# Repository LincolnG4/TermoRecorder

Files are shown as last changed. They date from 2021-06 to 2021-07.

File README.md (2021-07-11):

# TermoRecorder
The arduino records measurements from the thermocouples. It can run 4 measurements simultaneously. The measurements are saved into SD card in a '.CSV' file. A desktop software based on python creates an ETL pipeline to generate a dashboard to analyzes

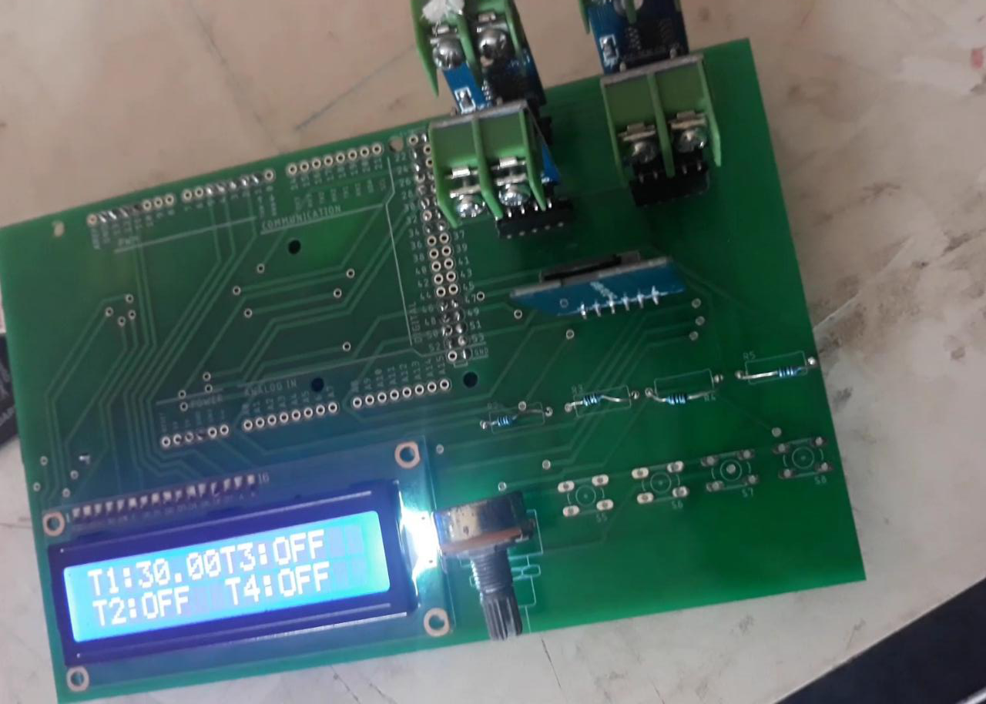
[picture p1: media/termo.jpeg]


## COMPONENTS :gear: 

- 1x Arduino Mega 2560
- 1x SD card module 
- 1x Display LCD 16x2
- 1x Potentiometer 10kOhms
- 4x 300Ω Resistors 
- 4x Module Max6675 K
- 4x Push Buttons

## PINOUT

| MAX6675 | MODULO 1 | MODULO 2 | MODULO 3 |  MODULO 4 |
| :--- | :----: | :----: | :----: | ---: |
| SCK | 33 | 31 | 32 | 26 |
| CS | 35 | 29 | 30 | 22 |
| SO | 34 | 27 | 28 | 24 |

| PUSH BUTTON 1 | PUSH BUTTON 2 | PUSH BUTTON 3 | PUSH BUTTON 4 |
| :--- | :----: | :----: | ---:  |
| 46 | 49 | 48 | 47 | 

| SD CARD | MODULO 1 |
| :--- | ---:  |
| CS | 53 | 
| SCK | 52 | 
| MOSI | 51 | 
| MOSO | 50 | 

LiquidCrystal lcd(12, 11, 5, 4, 3, 2);

## SETUP
*UNDER CONSTRUTION*

## HOW IT WORKS :chart_with_upwards_trend:

Every time that you click on push button the arduino starts to record a measurement. It can run 4 measurement simultaneously. The measurements are save into SD card in a `'.CSV'` file ([example file](https://raw.githubusercontent.com/LincolnG4/TermoRecorder/master/examples/DADOS3.CSV) or see more on `example` folder)  

## RUNNING DESKTOP SOFTWARE :computer:

### PREREQUISITES 
*UNDER CONSTRUTION* 

The desktop app is compose by 2 mainly codes:  

### 1. `create_measure.py` 

Drag all the `'.CSV'` generated by the arduino to the `create_measure.py` file.  
The `create_measure.py` will create a `'xlms'` file from the `'.CSV'` erasing all the NAN values and it creates a tab to each measurement.  
All blank rows in the `'xlms'` measurement file will be fill by interpolation during `plotter.py` running.

### 2. `plotter.py`

Drag all the `'xlms'` generated by step above. The command prompt will show up then write a name to your dashboard. 

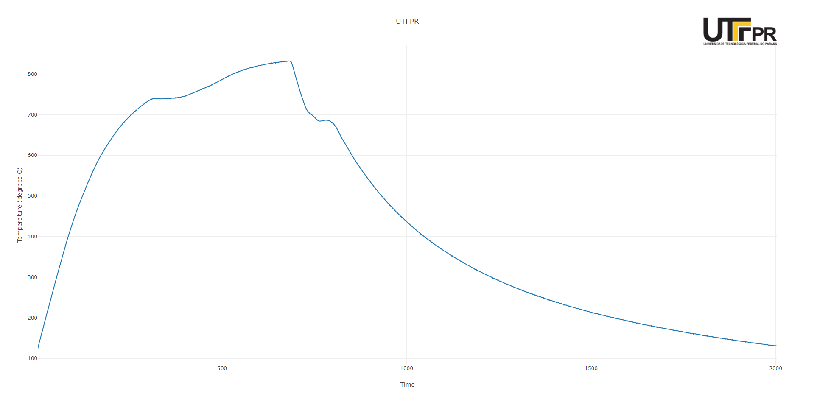
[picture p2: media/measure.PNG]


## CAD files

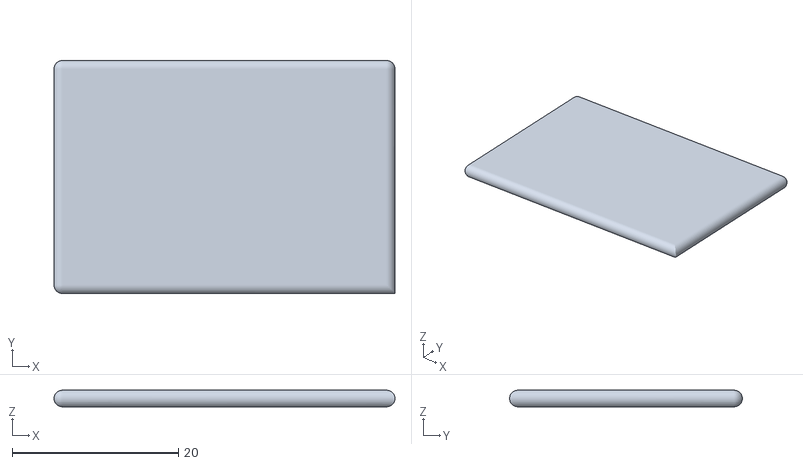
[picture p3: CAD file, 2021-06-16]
arduino/case/impressao/PortaUsb.STL
41.0 x 28.0 x 2.00

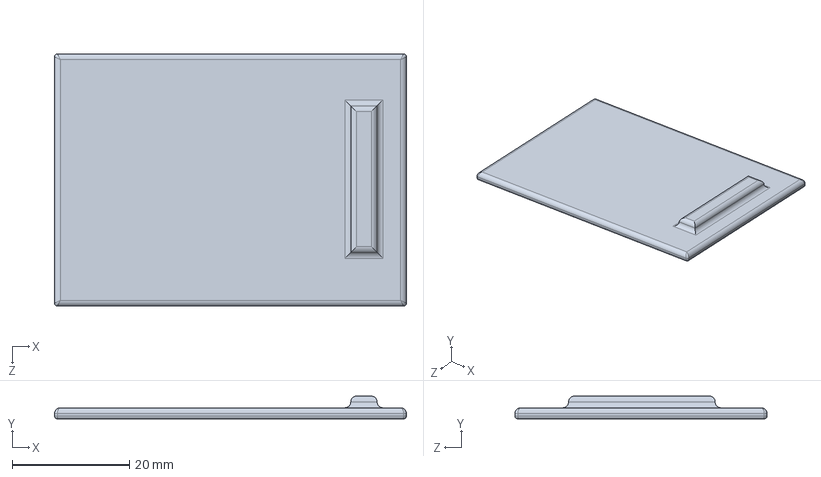
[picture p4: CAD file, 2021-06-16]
arduino/case/PortaSupBateria.SLDPRT
60.0 x 3.90 x 43.0 mm

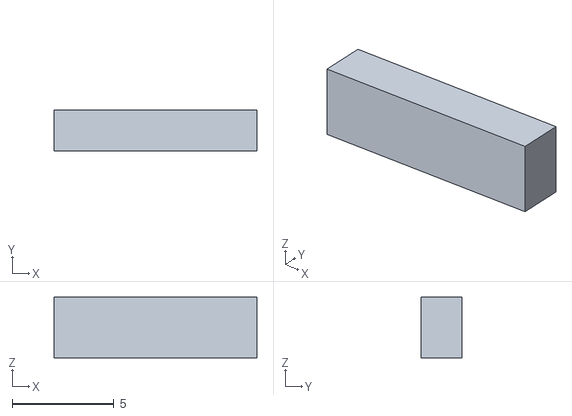
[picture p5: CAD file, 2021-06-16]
arduino/case/impressao/maçaneta.STL
10.0 x 2.00 x 3.00

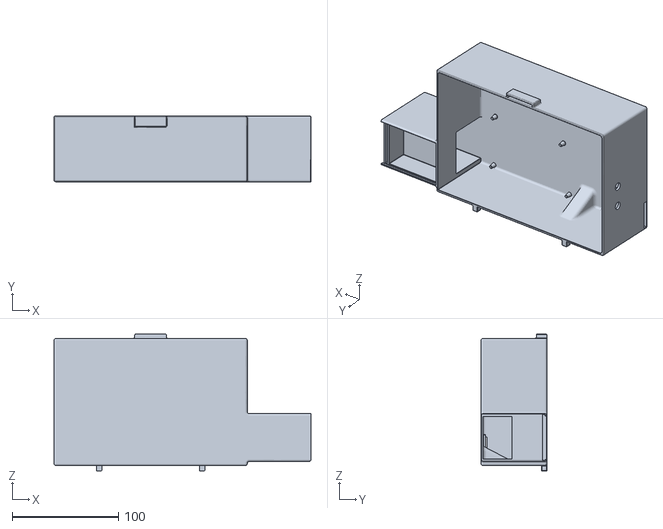
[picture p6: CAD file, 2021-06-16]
arduino/case/impressao/caixa.STL
242.0 x 62.0 x 129.0

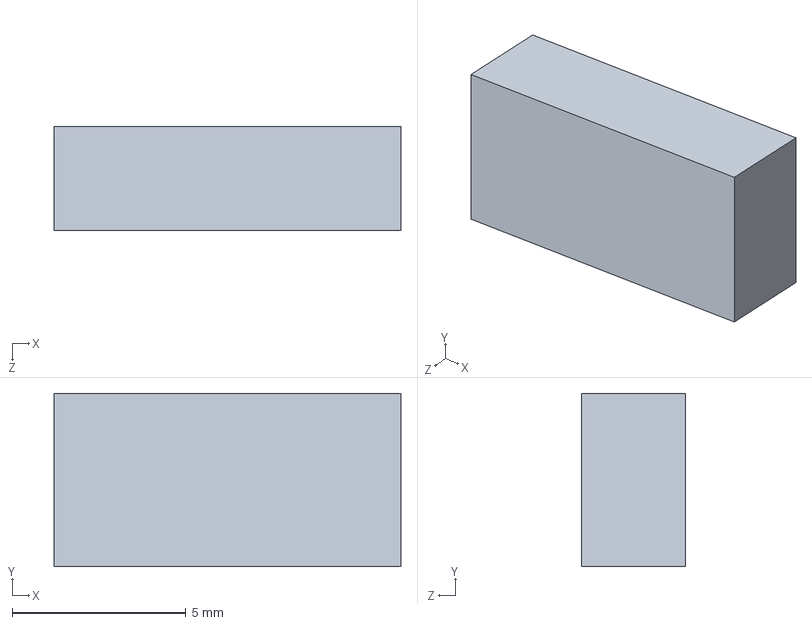
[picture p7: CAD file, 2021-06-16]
arduino/case/macaneta.SLDPRT
10.0 x 5.00 x 3.00 mm

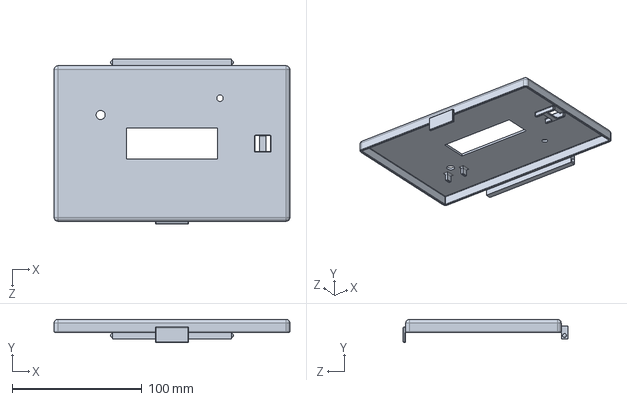
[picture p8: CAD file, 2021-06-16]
arduino/case/Tampa.SLDPRT
182.0 x 18.0 x 126.9 mm

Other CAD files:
arduino/case/PortaUsb.SLDPRT
arduino/case/maçaneta.SLDPRT
arduino/case/impressao/PortaSupBateria.STL
arduino/case/impressao/macaneta.STL
arduino/case/caixa.SLDPRT
arduino/case/impressao/Tampa.STL
arduino/case/Tampa.IGS
arduino/case/caixa.IGS

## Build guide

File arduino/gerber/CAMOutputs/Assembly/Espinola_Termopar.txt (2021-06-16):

Partlist exported from C:/Users/bruno/Desktop/UTFPR/2019.2/Projeto Espinola/Espinola_Termopar.sch at 15/11/2019 18:47

Qty Value               Device              Package       Parts              Description                                                                  MF MPN      OC_FARNELL OC_NEWARK SPICEPREFIX
4                       10-XX               B3F-10XX      S5, S6, S7, S8     OMRON SWITCH                                                                    B3F-1000 176432     36M3542              
4                       PINHD-1X5           1X05          JP2, JP3, JP4, JP5 PIN HEADER                                                                                                               
1                       PINHD-1X6           1X06          JP1                PIN HEADER                                                                                                               
4                       R-EU_0411/12        0411/12       R2, R3, R4, R5     RESISTOR, European symbol                                                                                     R          
1   ARDUINO_MEGA_R3FULL ARDUINO_MEGA_R3FULL ARDUINO_MEGA  B1                 Arduino Mega R3                                                                                                          
1   PC16S               PC16S               PC16S         R1                 POTENTIOMETER                                                                            4452940    unknown              
1   TUXGR_16X2_R2       TUXGR_16X2_R2       TUXGR_16X2_R2 DIS1               Tuxgraphics LCD display 16x2 characters reflective, without background light             unknown    unknown

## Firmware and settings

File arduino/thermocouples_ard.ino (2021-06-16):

/***************************************************************************
Criador: Gabriel Espinola
Email: g97santos@gmail.com
****************************************************************************/
/***************************************************************************

****************************************************************************/
#include <LiquidCrystal.h>
#include "max6675.h"
#include <SD.h>
#include <SPI.h>

                                                                                      /*Configurações de */// pino SD e Arquivo de dados SD
File dadosT1;
File dadosT2;
File dadosT3;
File dadosT4;
int pinCS = 53;                                                                         // PINO DO ARDUINO MEGA 
                                                                                      /*-------------------------------------*/
                                                                                        /* TIMER*/
float Te=0;                                                                             // tempo salvo no SD
//unsigned long timer=0;
float Te2=0;                                                                            // tempo salvo no SD
//unsigned long timer2=0; 
float Te3=0;                                                                             // tempo salvo no SD
//unsigned long timer=0;
float Te4=0;                                                                            // tempo salvo no SD
//unsigned long timer2=0;                                                               //Armazena os segundos transcorridos e inicia no 0 
 
unsigned long t1=0; 
unsigned long t2=0; 
unsigned long t3=0; 
unsigned long t4=0; 
unsigned long t5=0; 
unsigned long t6=0; 
unsigned long t7=0; 
unsigned long t8=0; 

//Botao1                                                                                /*Configurações do  */// Botao START
const int botao=46;
int var=0;                                                                              // valor instantaneo enviado pelo botão
int var2=0;                                                                             // valor guardado
int estado=0;
//Botao2                                                                               
const int botao2=49;
int var3=0;                                                                             
int var4=0;                                                                             
int estado2=0;                                                                          /*-------------------------------------*/
//Botao3                                                                              
const int botao3=48;
int var5=0;                                                                             
int var6=0;                                                                             
int estado3 =0; 
//Botao4                                                                              
const int botao4=47;
int var7=0;                                                                             
int var8=0;                                                                             
int estado4 =0; 

                                                                                        /*Configurações dos Pinos para o  */ //Módulo de Temperatura
//Termopar 1                                                                                      
int ktcSO=34;
int ktcCS=35;
int ktcCLK=33;
MAX6675 ktc(ktcCLK, ktcCS, ktcSO);
//Termopar 2                                                                                      
int ktcSO2=27;
int ktcCS2=29;
int ktcCLK2=31;
MAX6675 ktc2(ktcCLK2, ktcCS2, ktcSO2);
//Termopar 3                                                                                      
int ktcSO3=28;
int ktcCS3=30;
int ktcCLK3=32;
MAX6675 ktc3(ktcCLK3, ktcCS3, ktcSO3);
//Termopar 4                                                                                     
int ktcSO4=24;
int ktcCS4=22;
int ktcCLK4=26;
MAX6675 ktc4(ktcCLK4, ktcCS4, ktcSO4);

LiquidCrystal lcd(12, 11, 5, 4, 3, 2);
                                                                                        /*-------------------------------------*/
void setup() {                                                                          
Serial.begin(9600);                                                                                        /*Inicialização do*/// Botao START
pinMode(botao, INPUT);
pinMode(botao2, INPUT);                                                                 
pinMode(botao3, INPUT);
pinMode(botao4, INPUT);                                                                 /*-------------------------------------*/
                                                                                        /*Configurações para o*/// LCD 
lcd.begin(16, 2);
                                                                                        /*-------------------------------------*/
int ligasd=0;                                                                           /*Inicialização do*///  SD
pinMode(pinCS, OUTPUT);
  
if (SD.begin())                                                                         //Reconhecimento do cartao
  {
    ligasd=1;
  } else
  {   
    lcd.print("SD not found");
    delay(5000);
    lcd.clear();
    return;
  }
                                                                                        /*-------------------------------------*/                                                                                       /*-------------------------------------*/ 
}

void loop() {        
                                                                                        /*Inicialização do*///  COMANDO DO BOTAO LIGA/DELISG
delay(170);
var = digitalRead(botao);

if (var && !var2) 
    {
        var2 = 1;
        estado = 1 - estado;
        lcd.setCursor(3,0); 
        lcd.print("     ");
        //timer=0; 
        t1 = millis();
        Te=0;
    }
else if (!var){
    var2 = 0;
    }
    
if (estado == 0) 
    {
    lcd.setCursor(0,0); 
    lcd.print("A:OFF");
    }                                                                                   
    else 
    {

    t2 = millis();
    Te = t2 - t1; 
    Te = (Te/1000);                                                                                                                                                                                                                                    
    dadosT1 = SD.open("Dados1.csv", FILE_WRITE);                                         
    String dataString1 = String(Te) + ", " + ktc.readCelsius() ;
  
    lcd.setCursor(0,0);                                                            
    lcd.print("A:");                                                                                 
   
    if (dadosT1)                                                                       
       {                                                                                
       dadosT1.println(dataString1);
       dadosT1.close();                                                   
       }                                                                   
     
                                                                                     
    lcd.setCursor(2,0);             
    lcd.print(ktc.readCelsius());
    }                           
//________________________________________________________________________________________________________________________________________

var3 = digitalRead(botao2);

if (var3 && !var4) 
    {
        var4 = 1;
        estado2 = 1 - estado2;
        lcd.setCursor(3,1); 
        lcd.print("     ");
        //timer=0;
        t3 = millis(); 
        Te2=0;
    }
else if (!var3){
    var4 = 0;
}

if (estado2 == 0) 
    {
    lcd.setCursor(0,1); 
    lcd.print("B:OFF");
    }                                                                                   
    else 
    {
    t4 = millis();
    Te2 = t4 - t3; 
    Te2 = Te2/1000; 
                                                                     
    lcd.setCursor(0,1);                                                            
    lcd.print("B:");                                                                                    
                                                                                       
    dadosT2 = SD.open("Dados2.csv", FILE_WRITE);                                         
    String dataString2 = String(Te2) + ", " + ktc2.readCelsius() ;
                                                                                     
    if (dadosT2)                                                                       
       {                                                                                
       dadosT2.println(dataString2);
       dadosT2.close();                                                   
       }                                                                   
                                                                                     
    lcd.setCursor(2,1);             
    lcd.print(ktc2.readCelsius());
    }                                                                                 


//________________________________________________________________________________________________________________________________________

var5 = digitalRead(botao3);

if (var5 && !var6) 
    {
        var6 = 1;
        estado3 = 1 - estado3;
        lcd.setCursor(8,0); 
        lcd.print("                ");
        //timer=0; 
        t5 = millis();
        
        Te3=0;
    }
else if (!var5){
    var6 = 0;
}


if (estado3 == 0) 
    {
    lcd.setCursor(8,0); 
    lcd.print("C:OFF");
    }                                                                                   
    else 
    {
    
 
    t6 = millis();
     Serial.println(t6);
     Serial.println(t5); 
    Te3 = t6 - t5; 
    Te3 = Te3/1000;                                                                    
    lcd.setCursor(8,0);                                                            
    lcd.print("C:");                                                                                    
                                                                                     
    dadosT3 = SD.open("Dados3.csv", FILE_WRITE);                                         
    String dataString3 = String(Te3) + ", " + ktc3.readCelsius() ;
                                                                                        
    lcd.setCursor(10,0);             
    lcd.print(ktc3.readCelsius());                                                 
    Serial.println(dataString3);                                                                                  
    if (dadosT3)                                                                       
       {                                                                                
       dadosT3.println(dataString3);
       dadosT3.close();                                                   
       }                                                                   
       {
        }
    }   
    //________________________________________________________________________________________________________________________________________

var7 = digitalRead(botao4);

if (var7 && !var8) 
    {
        var8 = 1;
        estado4 = 1 - estado4;
        lcd.setCursor(8,1); 
        lcd.print("            ");
        //timer=0; 
        t7 = millis();
        Te4=0;
    }
else if (!var7){
    var8 = 0;
    }


if (estado4 == 0) 
    {
    lcd.setCursor(8,1); 
    lcd.print("D:OFF");
    }                                                                                   
    else 
    {
    t8 = millis();
    Te4 = t8 - t7; 
    Te4 = Te4/1000;
                                                                       
    lcd.setCursor(8,1);                                                            
    lcd.print("D:");                                                                                    
                                                                                       
    dadosT4 = SD.open("Dados4.csv", FILE_WRITE);                                         
    String dataString4 = String(Te4) + ", " + ktc4.readCelsius() ;
                                                                                     
    if (dadosT4)                                                                       
       {                                                                                
       dadosT4.println(dataString4);
       dadosT4.close();                                                   
       }                                                                   
                                                                                       
    lcd.setCursor(10,1);             
    lcd.print(ktc4.readCelsius());                                                 
             
    }    
    
                                                                  
} 
